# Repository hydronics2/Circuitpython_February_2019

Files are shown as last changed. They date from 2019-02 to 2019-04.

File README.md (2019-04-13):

# Circuitpython_February_2019
This is a soldering and programming class in Circuitpython

[github.com/hydronics2/circuitpython_february_2019](https://github.com/hydronics2/Circuitpython_February_2019)

This class occurs in two parts -- Soldering and Programming.

We'll be soldering parts and headers  onto a custom printed circuit board(PCB).  
Once complete, the microController (an Adfruit development board -  [ItsyBitsy M0](https://www.adafruit.com/product/3727)) sockets onto the PCB female headers.
When you connect the Adafruit M0 microController to your computer it shows up as an external hard drive with pre-loaded example scripts.

[Soldering Tutorial](https://github.com/hydronics2/Circuitpython_February_2019/blob/master/soldering/README.md)

[Programming Tutorial](https://github.com/hydronics2/Circuitpython_February_2019/blob/master/programming/README.md)

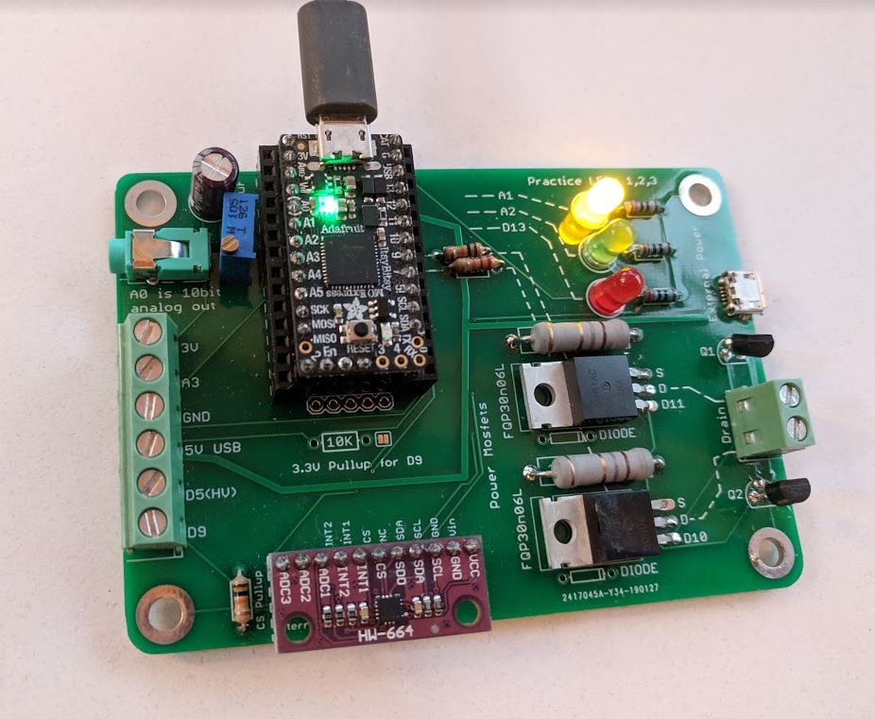
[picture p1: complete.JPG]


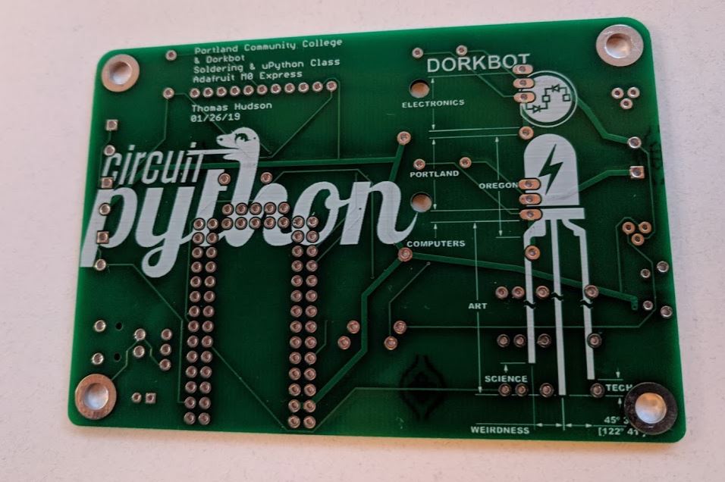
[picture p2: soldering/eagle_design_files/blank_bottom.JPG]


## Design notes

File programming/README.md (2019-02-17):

# CircuitPython

I uploaded the above python scripts onto your Adafruit M0 board. When you plug the unit into your board it appears as a flash drive.

Download and install the [MU editor](https://learn.adafruit.com/welcome-to-circuitpython/installing-mu-editor) if you have not done so already.

## code.py
LOAD the code.py script. Code.py determines which scripts run. Uncomment the files you would like to run.
###
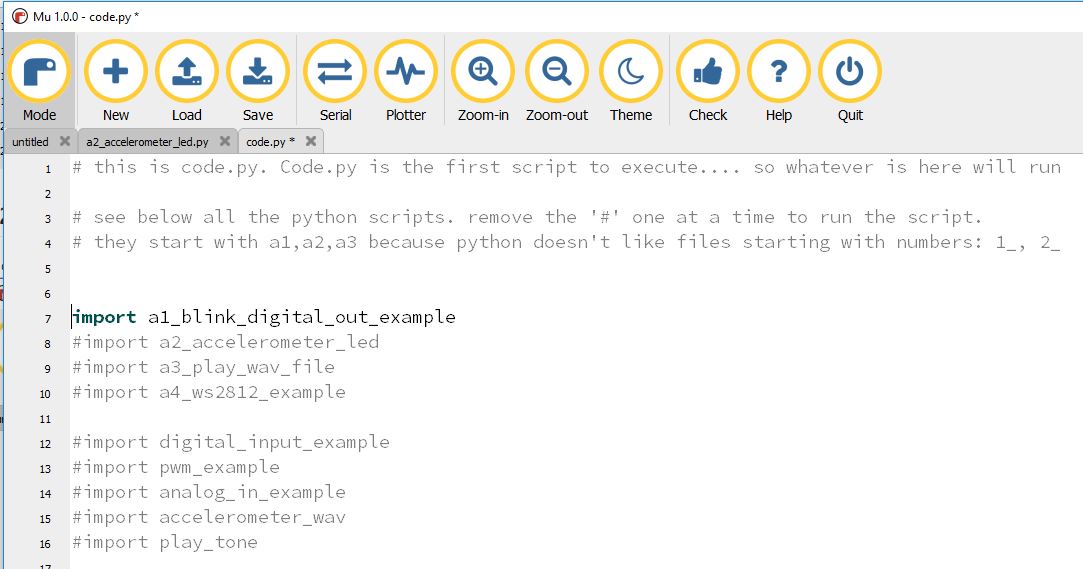
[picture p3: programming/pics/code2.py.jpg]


# 
## a1_blink_digital_out_example
LOAD the "a1_blink_digital_out_example.py" script that's currently running. It blinks the LED on pin 13. An internal LED also blinks. Try blinking the other LEDs on pins A1 and A2. In my case I labeled them greenLed and yellowLed. Hit the SERIAL button to see the print statements.
###
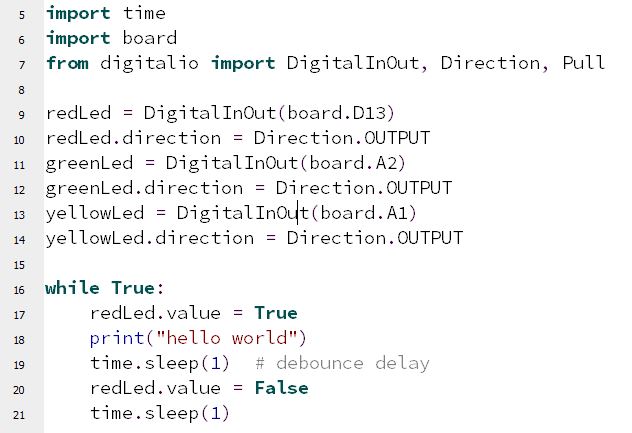
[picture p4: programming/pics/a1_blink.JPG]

# 

## a2_accelerometer_led
Modify the code.py script and uncomment a2_accelerometer_led.
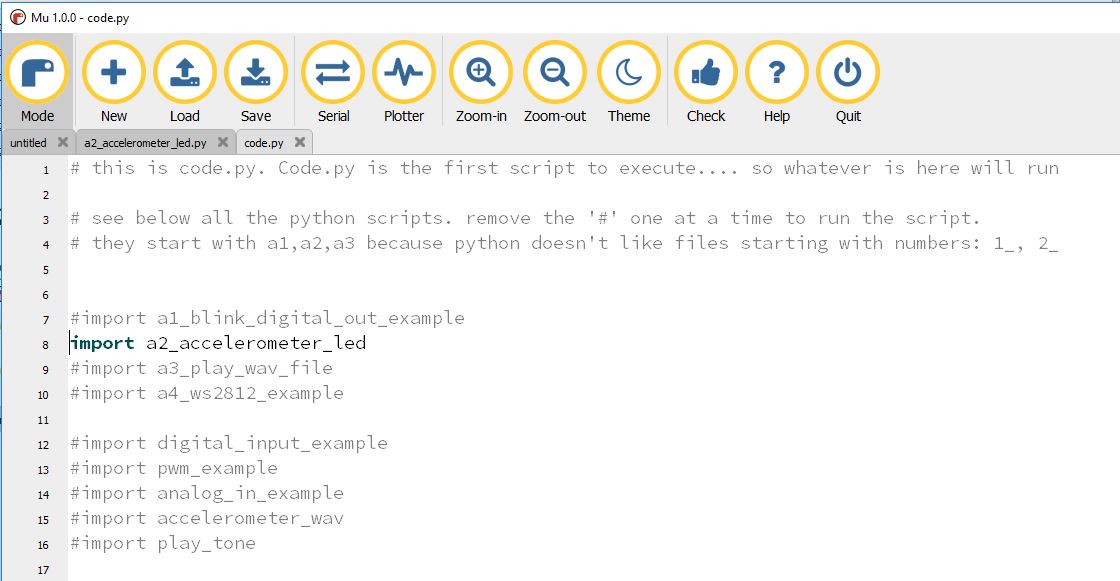
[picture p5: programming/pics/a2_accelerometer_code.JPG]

###
The script lights up an LED with increasing tilt.
When you use a print statement with double perenthesis it allows the data to the plotter; such as, print((x,y,z)).
###
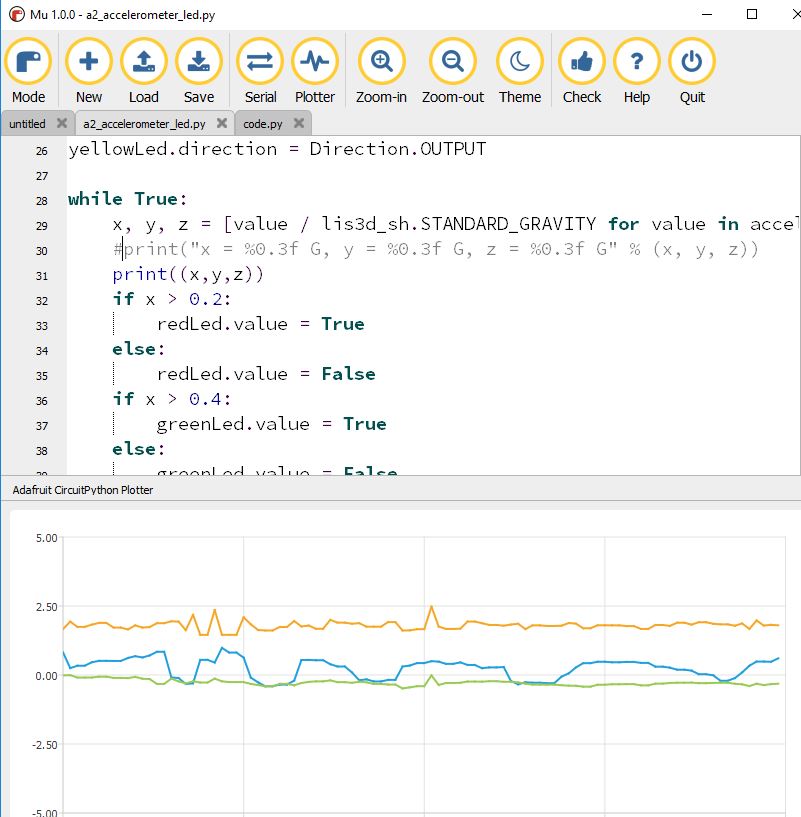
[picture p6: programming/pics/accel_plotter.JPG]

# 

## a3_play_wav_file
Modify the code.py script and unomment a3_play_wav_file
###
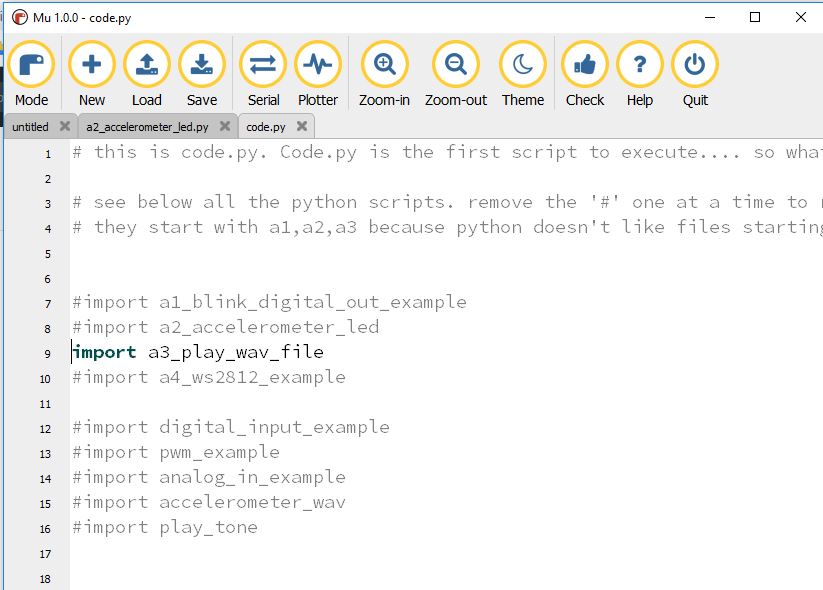
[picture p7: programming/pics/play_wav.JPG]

###
5 wav files for you try. They are in the sounds folder. Uncomment the files to play each one.. and/or make your own. 
Save files as 22 KHz or less because the circuitpython can't handle more data than that and the DAC(digital-to-analog-converter) output is 10-bit so anything over 16-bit will just take up room without better quality.
###
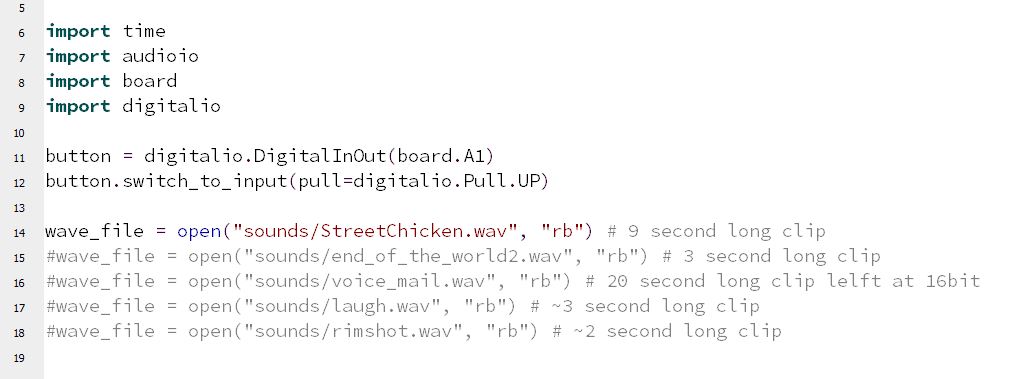
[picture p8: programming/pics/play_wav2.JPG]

# 

## a4_ws2812_example
Modify the code.py script and unomment a4_ws2812_example
###
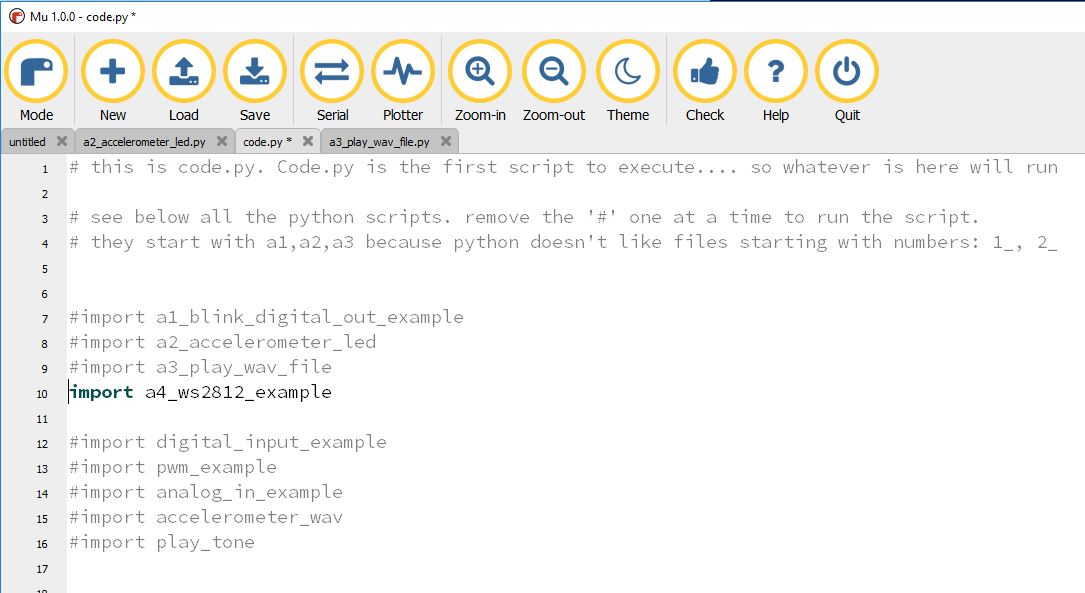
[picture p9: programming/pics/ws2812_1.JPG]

###
solder three leads onto your LED strip on the correct side (start of the arrow). Insert the LEDs into the screw headers.
LOAD the sketch and modify the "num_leds" variable to the number of LEDs in your strip.
The red, green, and blue LEDs can have values from 0 to 255.
###
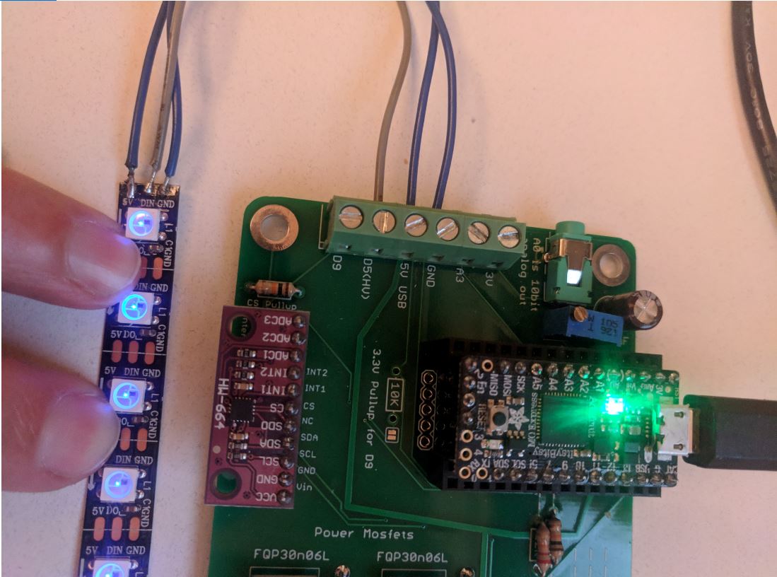
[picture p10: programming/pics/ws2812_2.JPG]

# 

## analog_in_example
Modify the code.py script and unomment analog_in_example.
Try plugging in both the potentiometer and photocell to see how the analog-to-digital converter(ADC) on pin A3 interprets the signals.
###
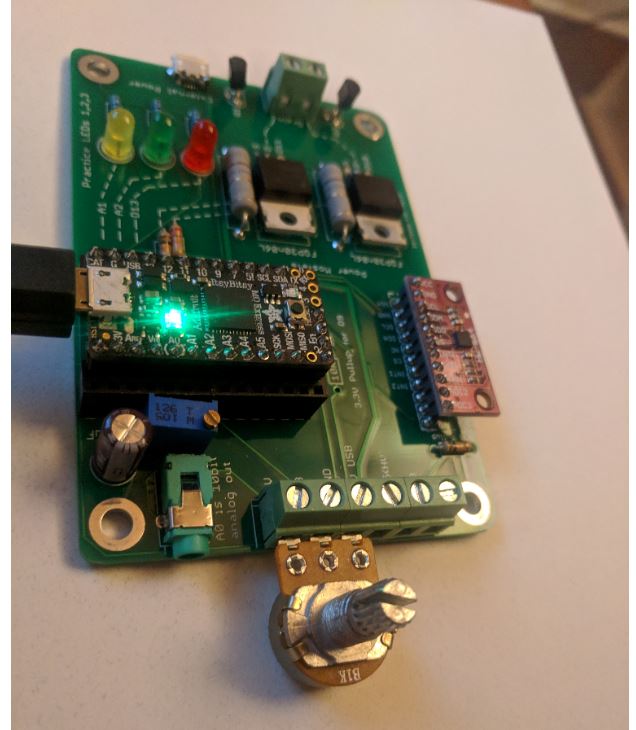
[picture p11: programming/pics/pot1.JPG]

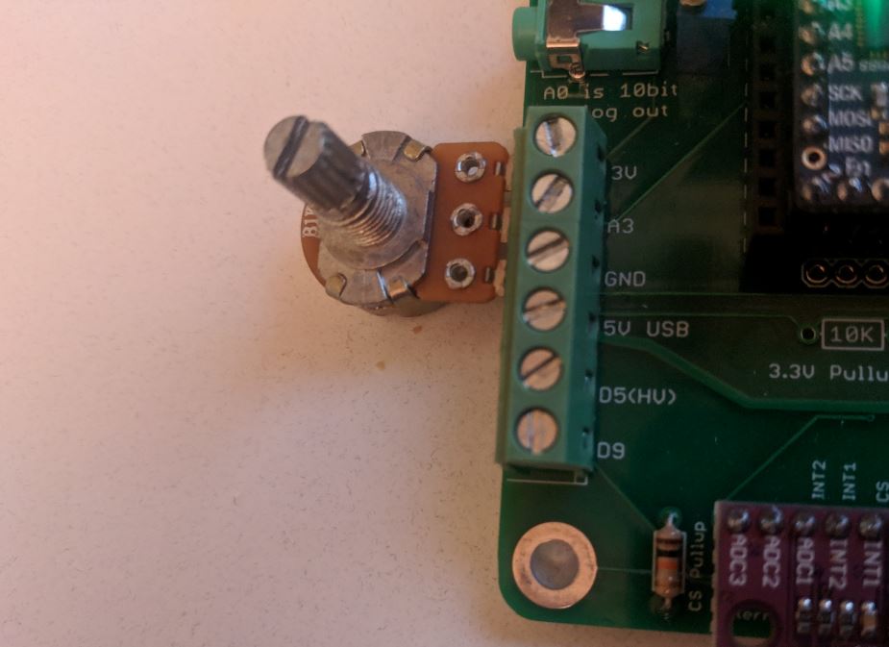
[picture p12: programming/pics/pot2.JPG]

###
Make the photocell voltage divder using a photocell and a 10k resistor.
###
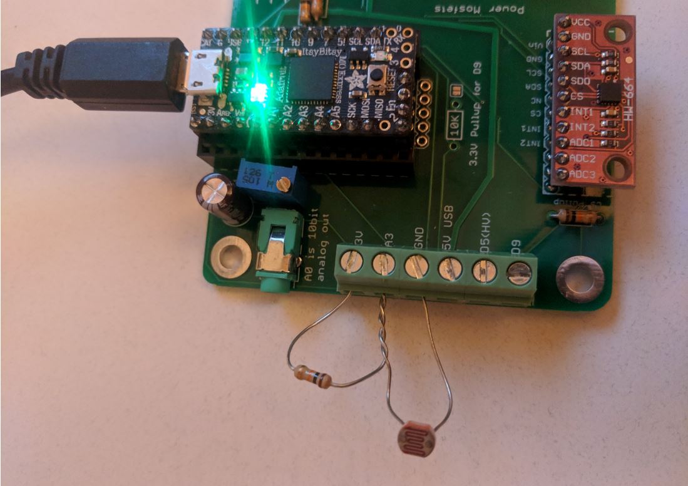
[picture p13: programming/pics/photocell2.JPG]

You can see the data on the plotter by using the print statement with extra perenthesis and a comma, "print((analogValue,))"
###
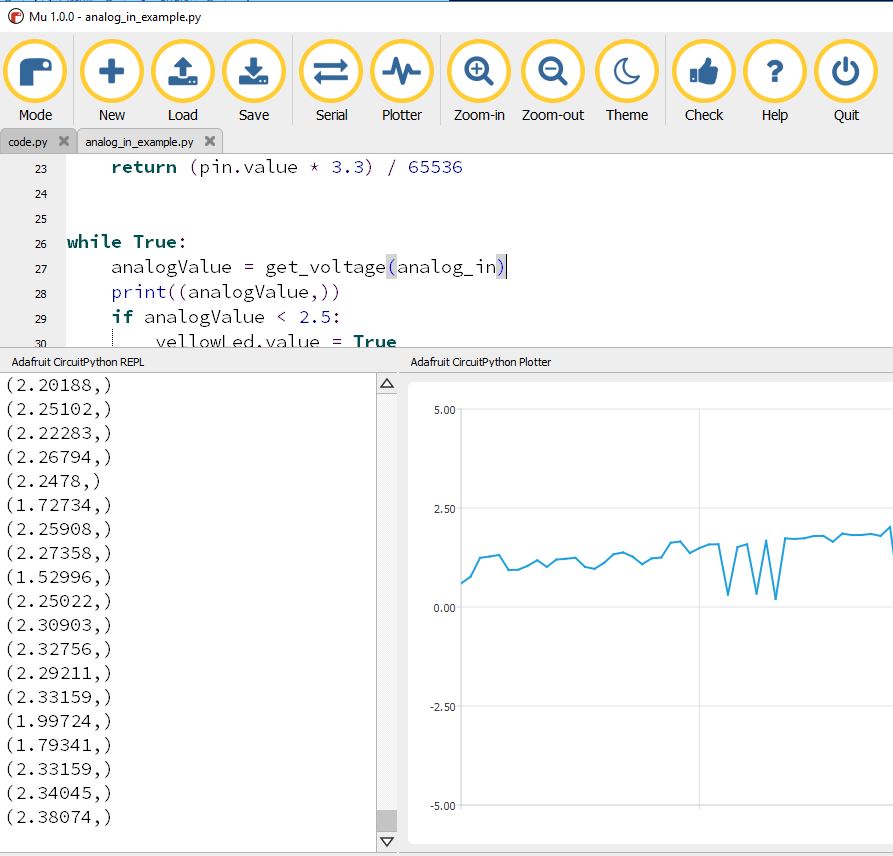
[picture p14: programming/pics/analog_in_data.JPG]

#

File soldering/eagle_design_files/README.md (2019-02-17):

# Printed Circuit Board

This circuit board was designed in Eagle.

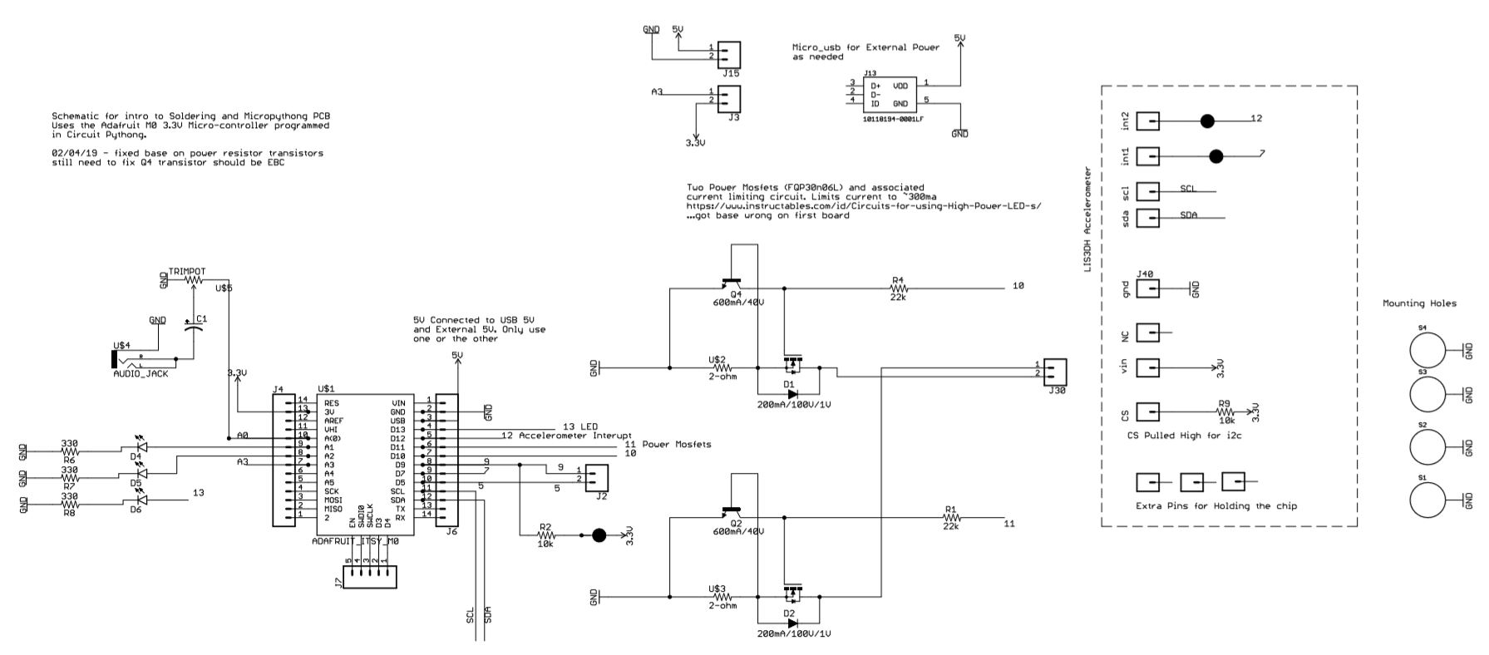
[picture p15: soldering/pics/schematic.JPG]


02/16/19 
- corrected the base transistor. It needs to be connected to the source pin of the mosfet. Have not routed the signal. Incorrectly routed on version 1 board
- still need to correct the Q1 and Q2 silkscreen. Sparkfun's NPN trnsistor did not use emitter-base-collector??? ridiculous!

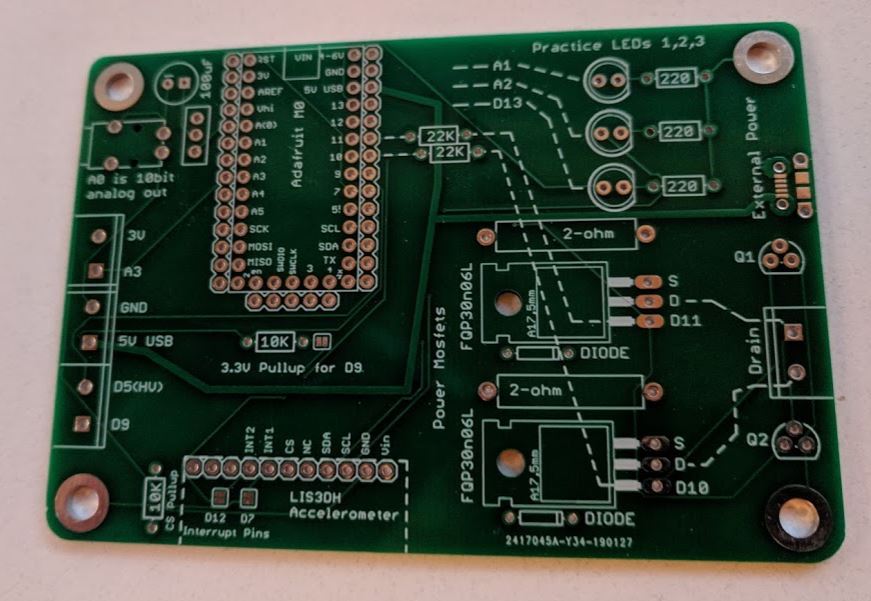
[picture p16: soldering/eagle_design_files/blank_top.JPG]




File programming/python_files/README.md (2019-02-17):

# Circuitpython files

[Adafruit Tutorial](https://learn.adafruit.com/circuitpython-essentials)

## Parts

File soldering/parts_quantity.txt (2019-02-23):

itsybits qty(8)
WS8212 Strip ~5meters
2-pin 5.08mm headers qty(122)
1/8" audio jacks qty(76)
16+ pins male headers qty(62)
16pin dual row female headers qty(101)
USB micro cables mix qty(15) not all tested
100k trim pots qty(7)
10k potentiometers qty(12)
5mm LEDs qty(1000)
photocels qty(50+)
10K and 220ohm resistors... qty(plenty?)
10uF 50v and 10uf 25V qty(~100)
pin-to-pin Jumper wires qty(100+)

LIS3D_SH Accelerometers qty(3)
usb drives qty(5)
circuitPython PCBs 1/26/10 qty(4)

future class
2ohm 1/2W resistors qty(100) S2HCT-ND
FQP power mosfets qty(unopened package ~100?)
large 12mm buttons qty(40)

Need
leaded solder

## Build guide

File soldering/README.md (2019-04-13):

# Soldering

Parts list
- [itsybitsy M0](https://www.adafruit.com/product/3727)
- [LIS3DSH Accelerometer](https://www.aliexpress.com/item/CJMCU-LIS3DSH-High-resolution-Three-axis-Accelerometer-Triaxial-Accelerometer-Module-LIS3DH/32879796761.html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)
- [14 pin double row headers](https://www.aliexpress.com/item/100-pcs-2-54-mm-0-100-Pitch-2x14-28-Pin-Dual-Row-PCB-Female-Header/32807834427.html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)
- [2-pin terminal blocks](https://www.aliexpress.com/item/50PCS-PCB-Screw-Terminal-Block-Connector-KF127-2P-pitch-5-08MM-0-2inch-Green-5mm-KF127/32791211110.html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)
- [WS2812 LED Strip](https://www.aliexpress.com/item/5m-DC5V-WS2812B-led-pixel-srip-non-waterproof-74pcs-WS2812B-M-with-60pixels-BLACK-PCB-only/1667439010.html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)
- [FQP30N06 Power Mosfet TO-220](https://www.aliexpress.com/item/Free-shipping-100pcs-lot-FQP30N06-30N06-TO-220-IC/32863833006.html?)
- [3.5 mm (1/8") jack](https://www.aliexpress.com/item/Free-shipping-100pcs-lot-FQP30N06-30N06-TO-220-IC/32863833006.html?)
- [trim pot ~1K](https://www.aliexpress.com/item/Free-shipping-100PCS-3296W-1-103LF-3296W-3296-10K-OHM-Trimpot-Trimmer-Potentiometer/32285032567.html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)
- 100uF 16V Capacitor
- 10k pullup resistors
- 220 ohm current limiting LED resistors
- [2ohm, 1/2watt Power Sensing Resistor](https://www.digikey.com/product-detail/en/stackpole-electronics-inc/CFM12JT2R00/S2HCT-ND/2617415)
- [PN2222A Transistor](https://www.aliexpress.com/item/100pcs-PN2222A-TO-92-PN2222-TO-92/32888878276.html?)
- [micro USB connector](https://www.digikey.com/product-detail/en/amphenol-icc-fci/10118194-0001LF/609-4618-6-ND/2785383)

[Here's the schematic](https://github.com/hydronics2/Circuitpython_February_2019/blob/master/soldering/eagle_design_files/PCB_schematic.pdf)

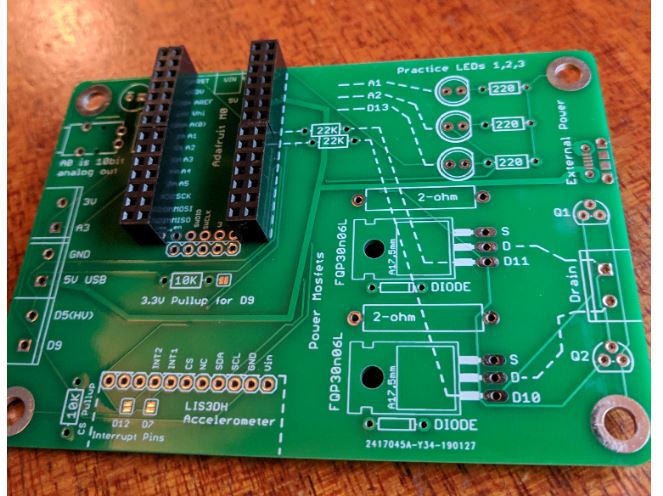
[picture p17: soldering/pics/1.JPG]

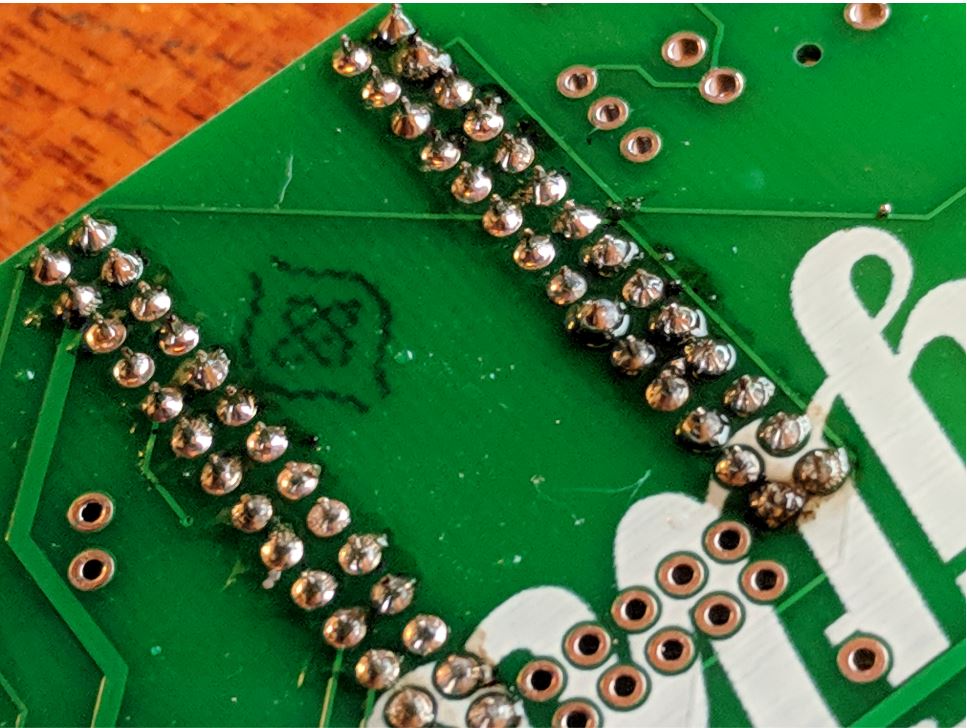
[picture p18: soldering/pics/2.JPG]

Solder on pins should look concave. NOT BALLS. Use your solding iron to wick away excess solder.
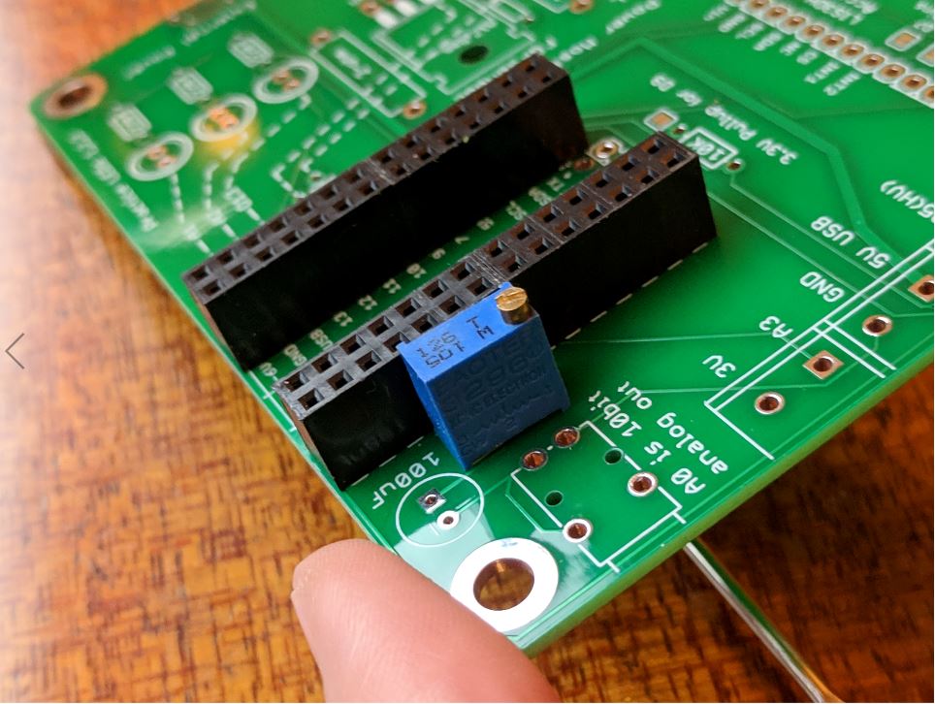
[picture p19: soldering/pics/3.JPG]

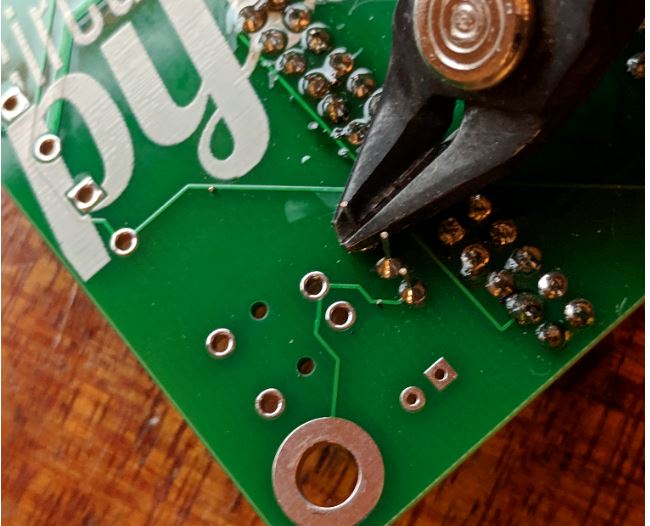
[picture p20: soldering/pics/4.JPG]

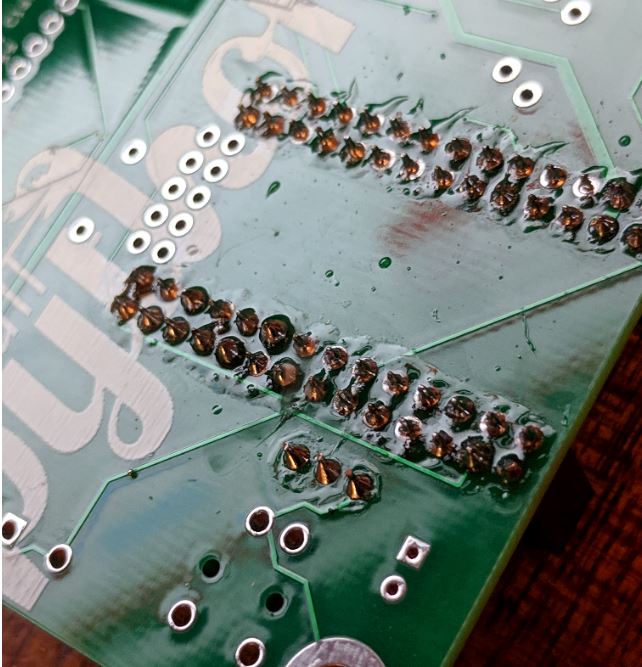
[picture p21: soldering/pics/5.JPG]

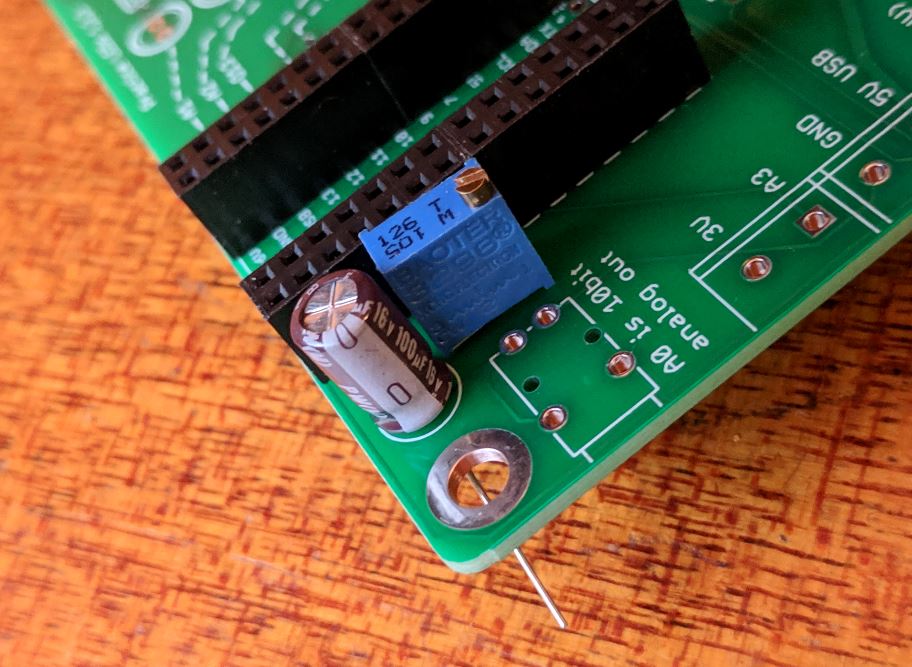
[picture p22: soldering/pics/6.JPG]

Your cap maybe 47uF cause that's what I had although the adafruit tutorial recomends 100uF 16V.
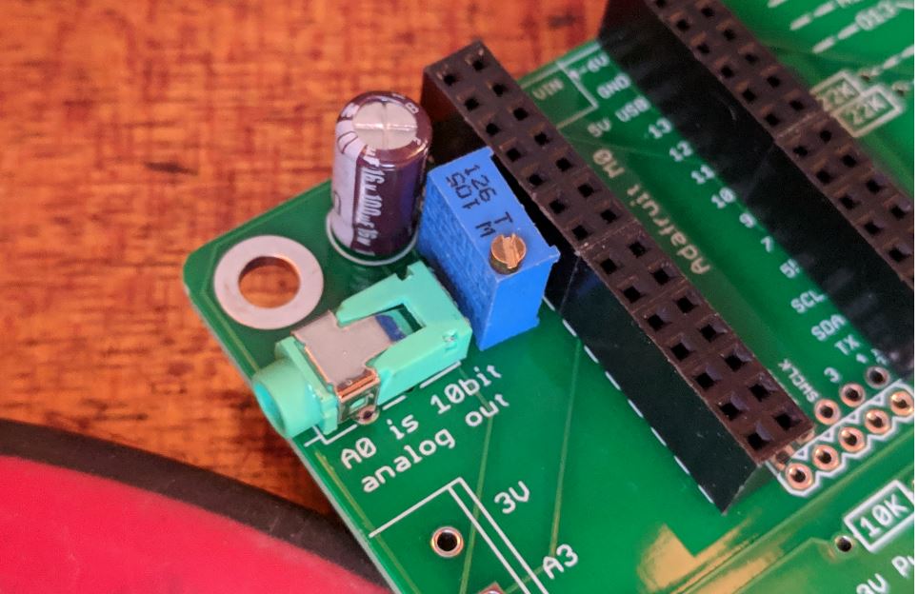
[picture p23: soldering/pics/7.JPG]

[](https://github.com/hydronics2/Circuitpython_February_2019/blob/master/soldering/pics/8.JPG)
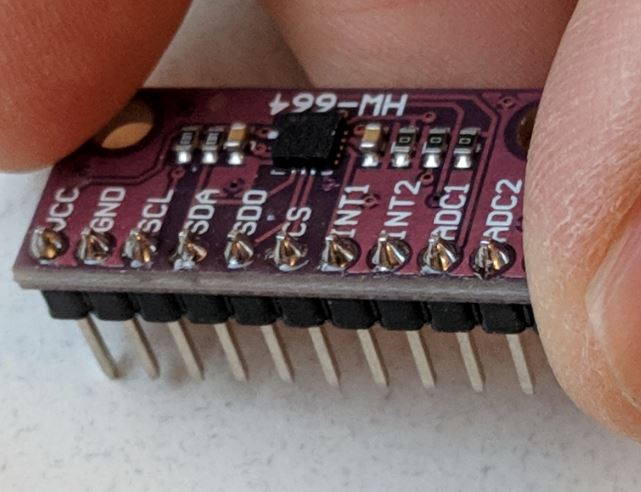
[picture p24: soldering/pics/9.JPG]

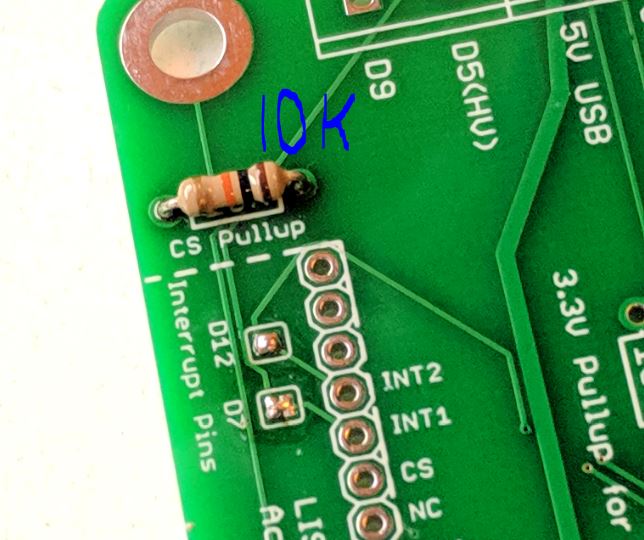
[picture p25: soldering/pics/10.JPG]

The resistor color band for 10K is brown-black-orange. The last color (gold in this picture) indicates tollerance (1%, 5%, etc).
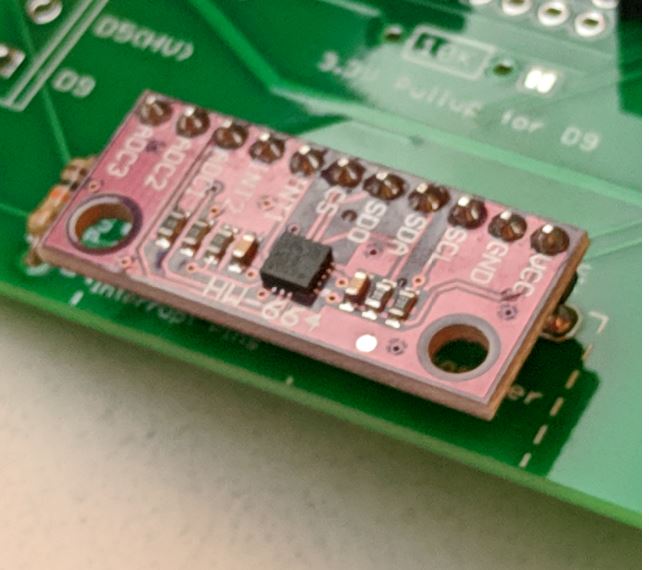
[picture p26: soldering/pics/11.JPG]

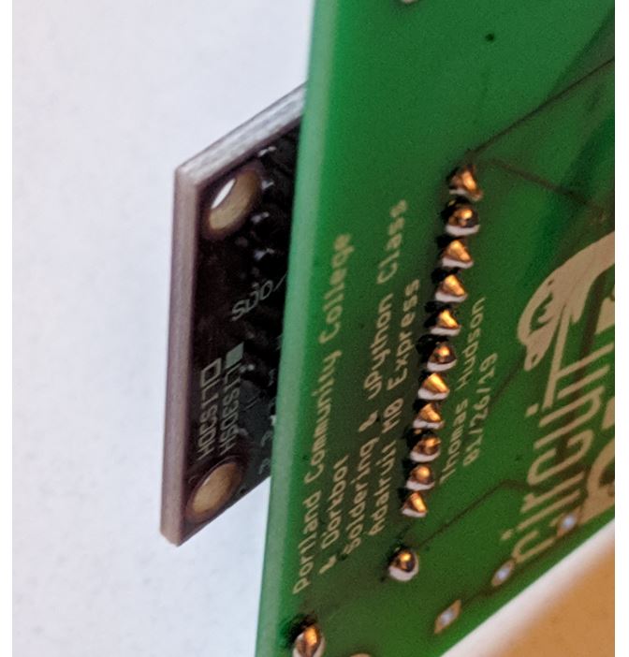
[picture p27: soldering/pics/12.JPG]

Soldering the accelerometer board ~1/8" above the PCB keeps the pins looking nice on the bottom. 
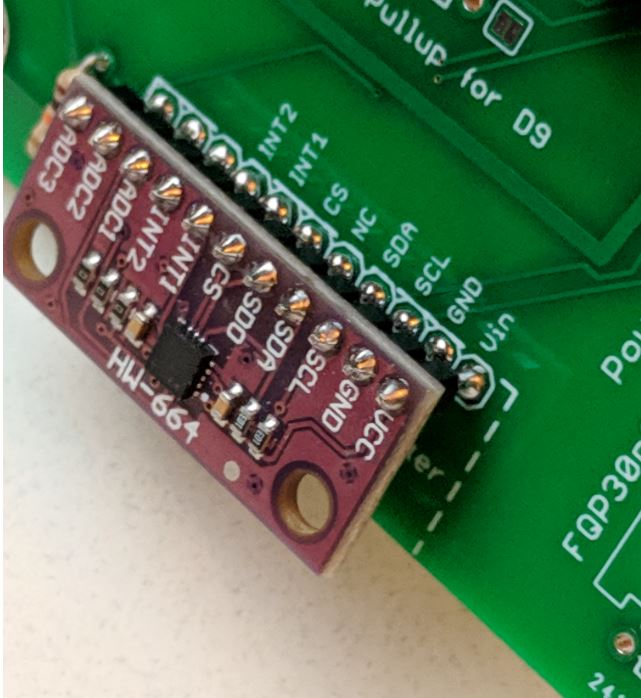
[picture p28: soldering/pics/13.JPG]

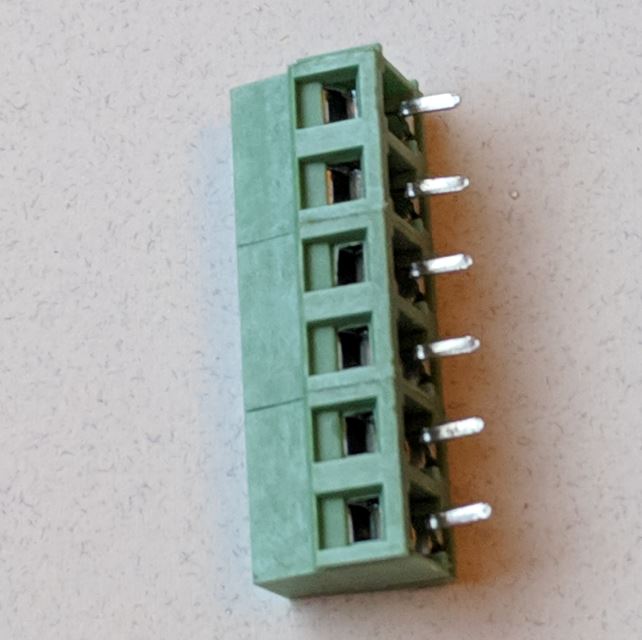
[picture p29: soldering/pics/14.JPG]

These 5.08mm screw terminals slide together.
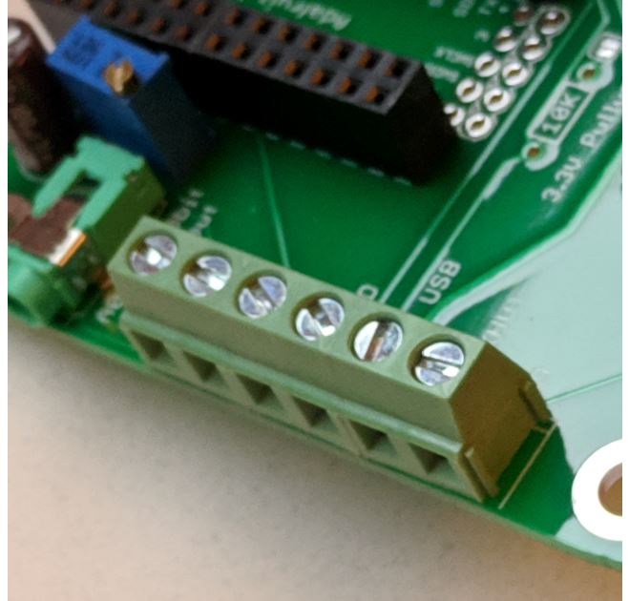
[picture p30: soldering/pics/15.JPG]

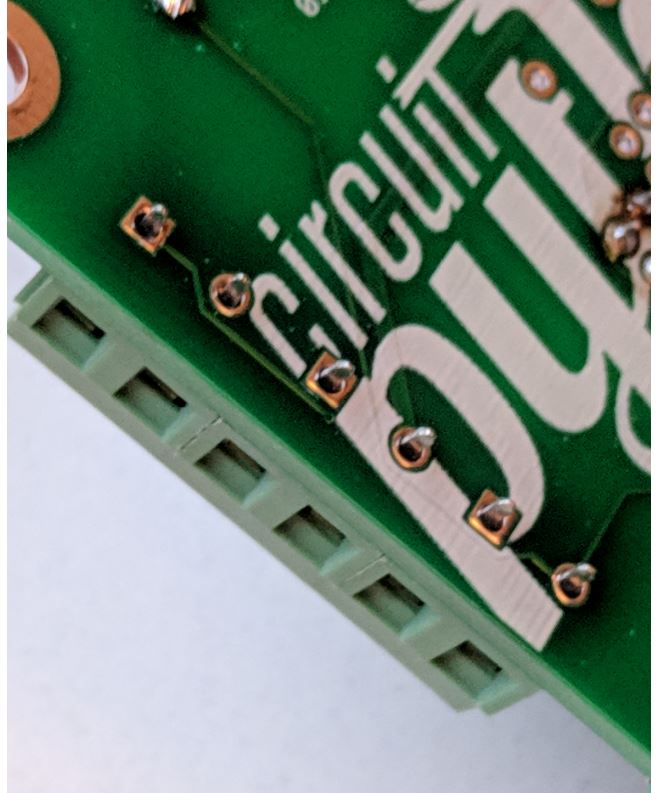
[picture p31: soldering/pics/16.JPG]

Solder all those Pins!
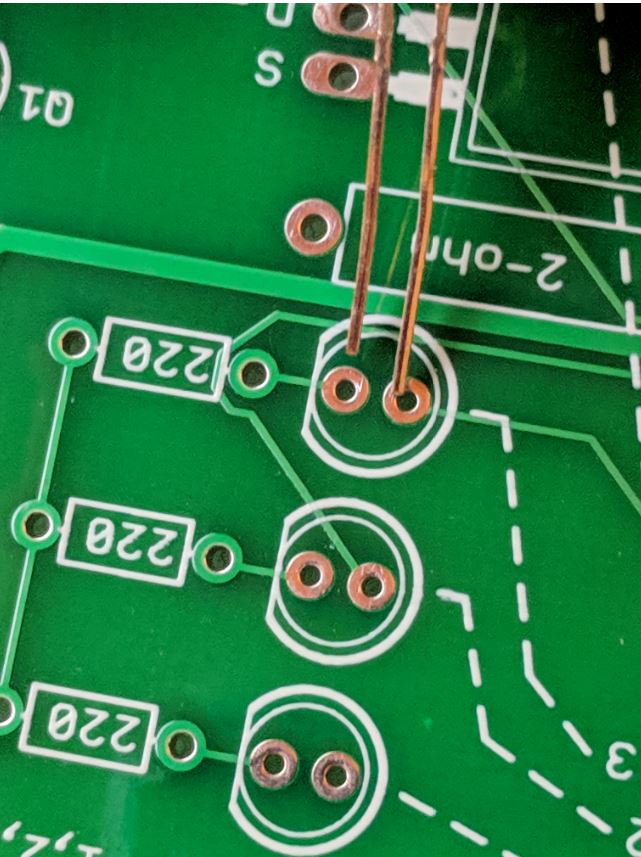
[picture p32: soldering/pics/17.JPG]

Choose wichever color LEDs you like. The longer lead is positive.
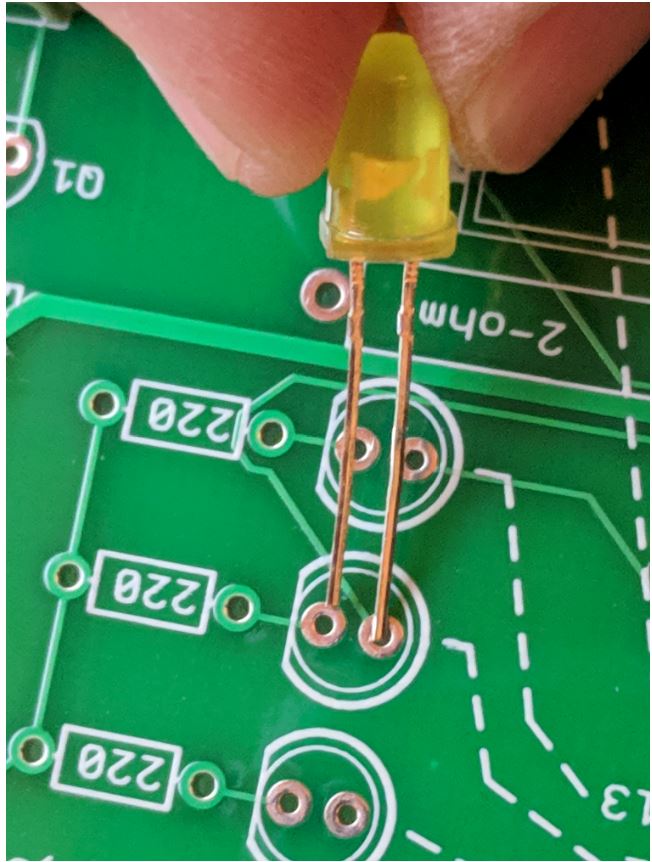
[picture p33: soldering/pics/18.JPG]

The notch in the LED is negative and matches the notch in the silkscreen.
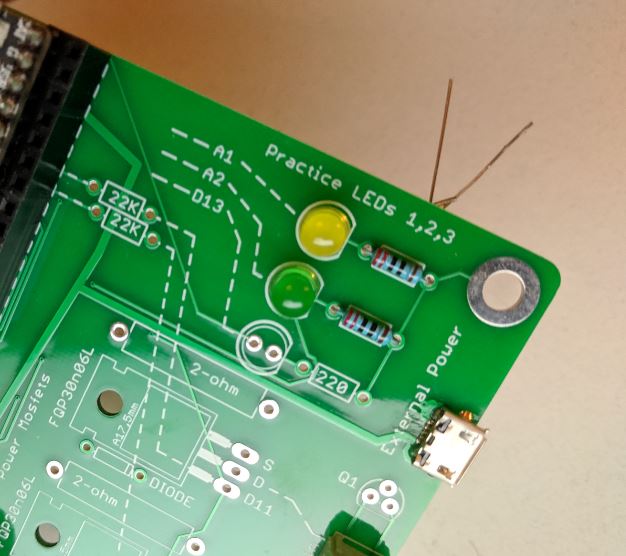
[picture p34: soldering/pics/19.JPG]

The current limiting resistors for the LEDs is 220ohms. The color band for 220 is red-red-black.
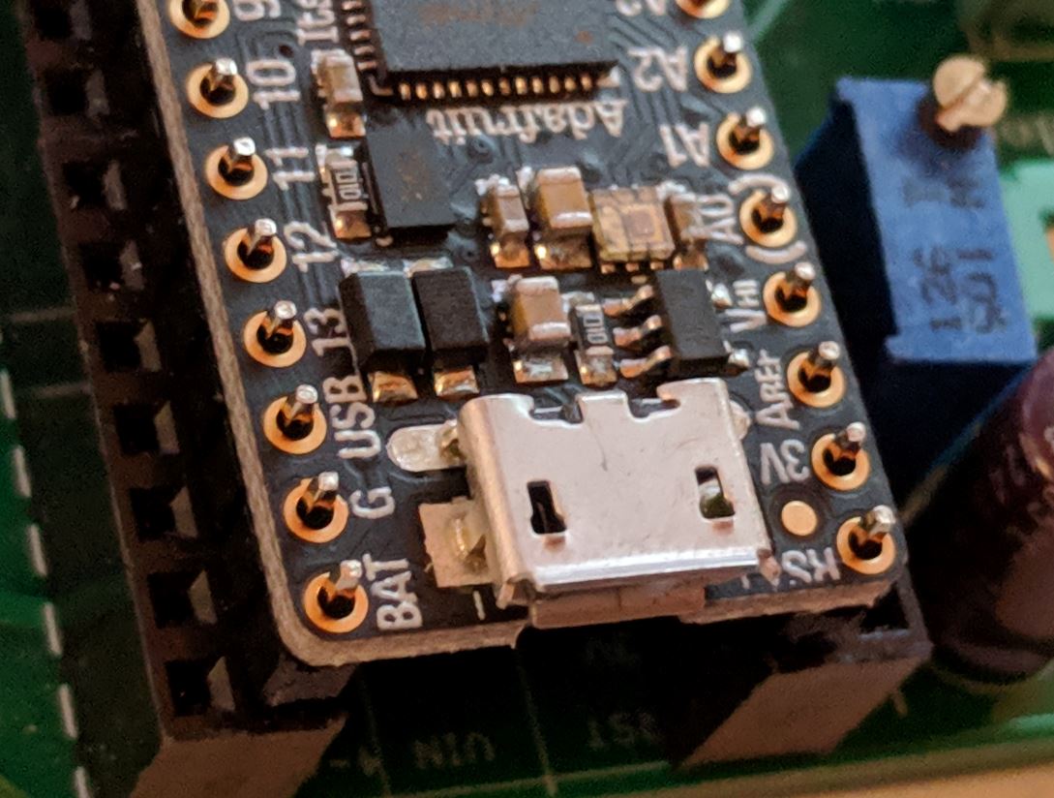
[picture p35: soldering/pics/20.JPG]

Solder all those Pins!
Break the male headers into 14 pins to match the length of the uController and solder the pins to the uController.
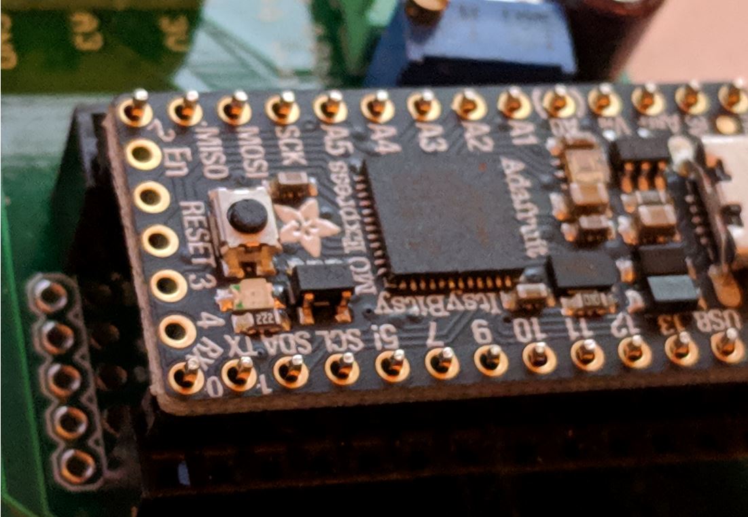
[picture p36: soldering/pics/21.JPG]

Solder all those Pins!
Break 2 pins off the 16pin male headers to get 14 pins is all you need. You're Done.
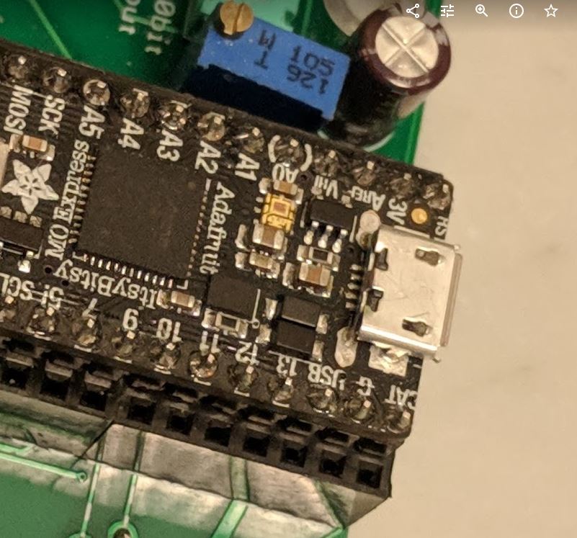
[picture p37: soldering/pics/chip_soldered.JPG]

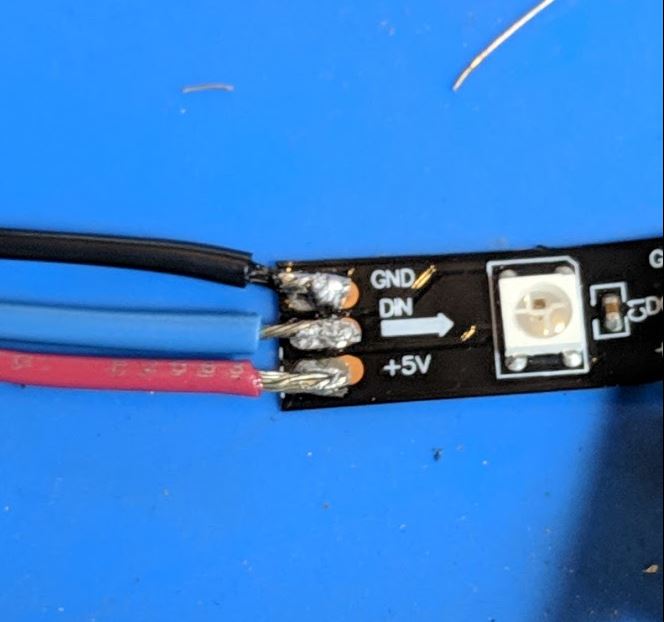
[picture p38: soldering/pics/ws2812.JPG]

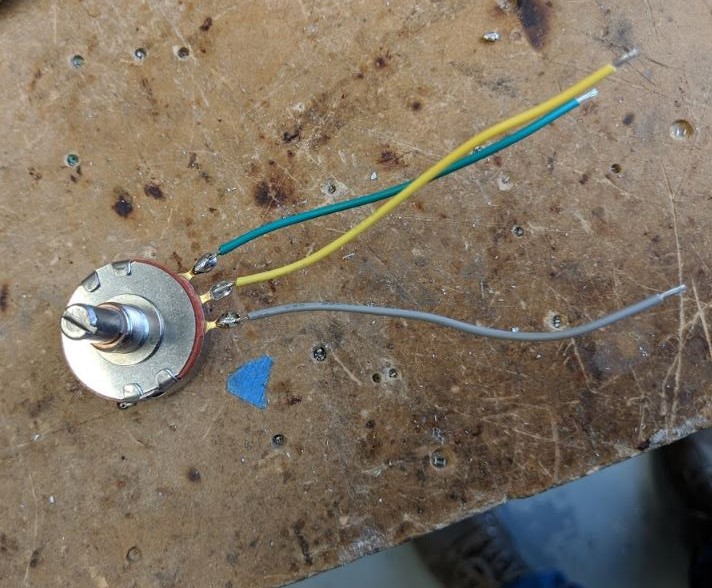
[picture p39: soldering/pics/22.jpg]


Solder 3 wires onto the potentiometer.

That's it. We're all finished! We're leaving a few footprints unpopulated for this class.

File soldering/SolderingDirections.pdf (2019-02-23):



Solder on pins should look concave. NOT BALLS. Use your solding iron to wick away excess solder.





Your cap maybe 47uF cause that's what I had although the adafruit tutorial recomends 100uF 16V.

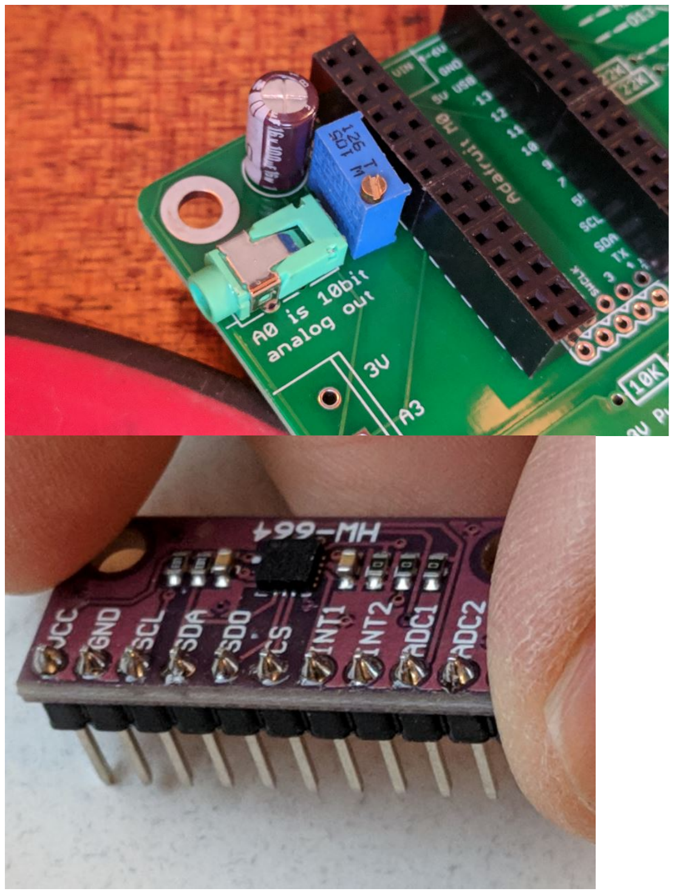
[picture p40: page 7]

The


resistor color band for 10K is brown-black-orange. The last color (gold in this picture) indicates tollerance (1%, 5%, etc).


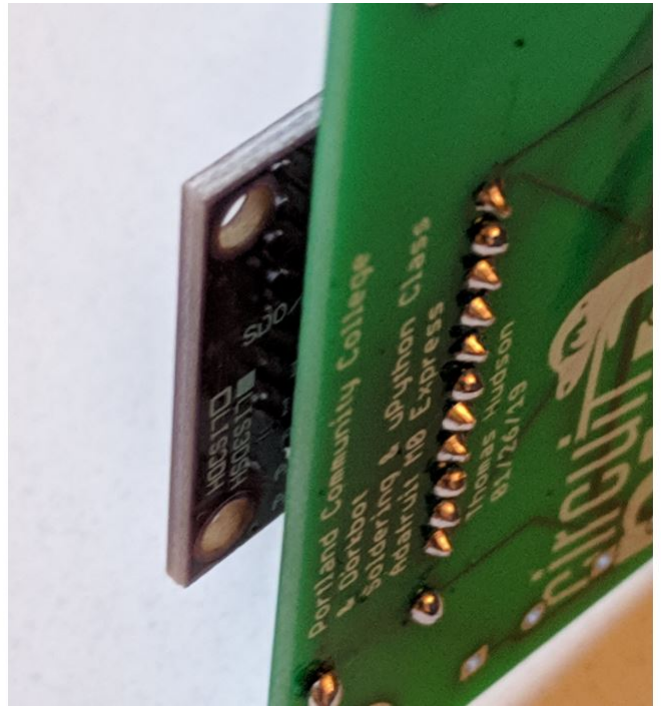
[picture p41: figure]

Soldering the accelerometer board ~1/8" above the PCB keeps the pins looking nice on the bottom.


These


5.08mm screw terminals slide together.


Choose
wichever color LEDs you like. The longer lead is positive.


The notch
in the LED is negative and matches the notch in the silkscreen.

The current


limiting resistors for the LEDs is 220ohms. The color band for 220 is red-red-black.


Break the male headers into 14 pins to match the length of the uController and solder the pins to the uController.


Break 2 pins off the 16pin male headers to get 14 pins is all you need. You're Done.



We're not going to solder the rest of the parts unless we have more time or you want to do extra.

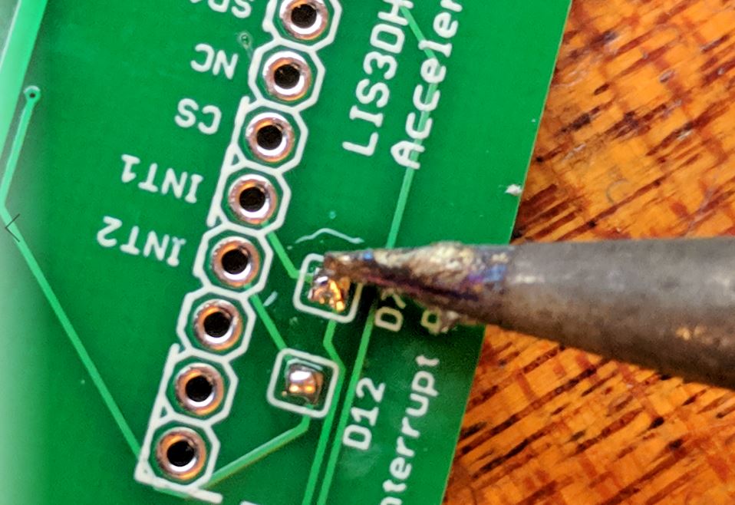
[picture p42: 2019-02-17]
soldering/pics/8.JPG

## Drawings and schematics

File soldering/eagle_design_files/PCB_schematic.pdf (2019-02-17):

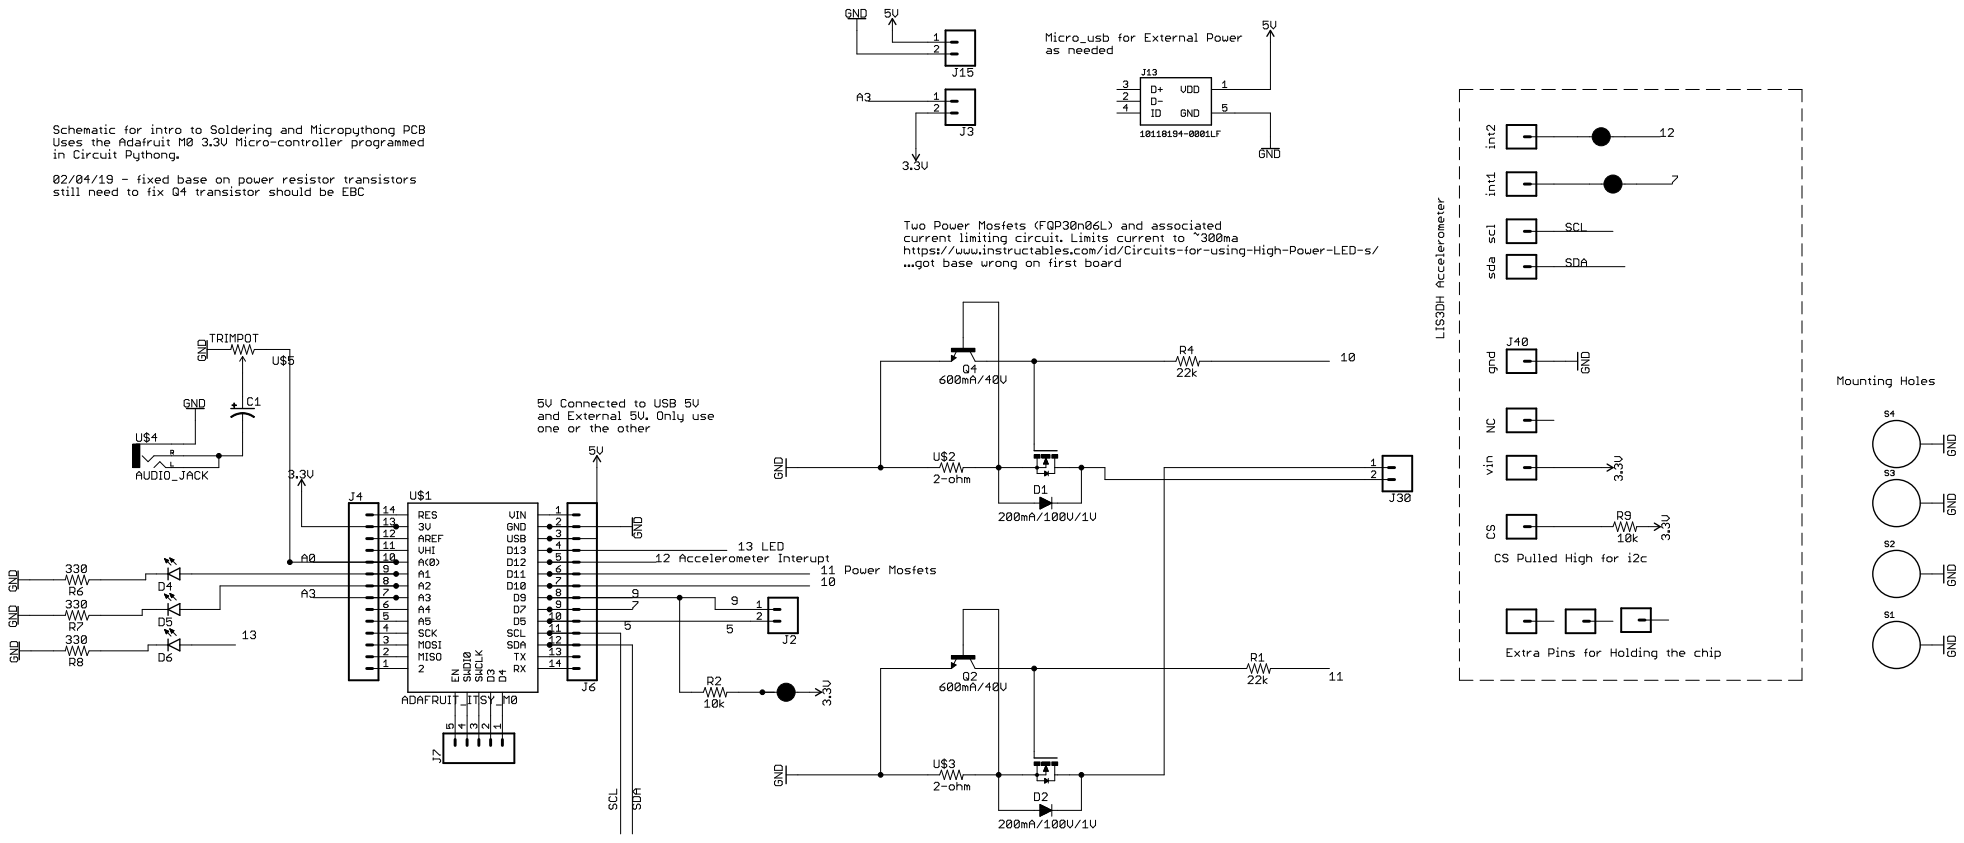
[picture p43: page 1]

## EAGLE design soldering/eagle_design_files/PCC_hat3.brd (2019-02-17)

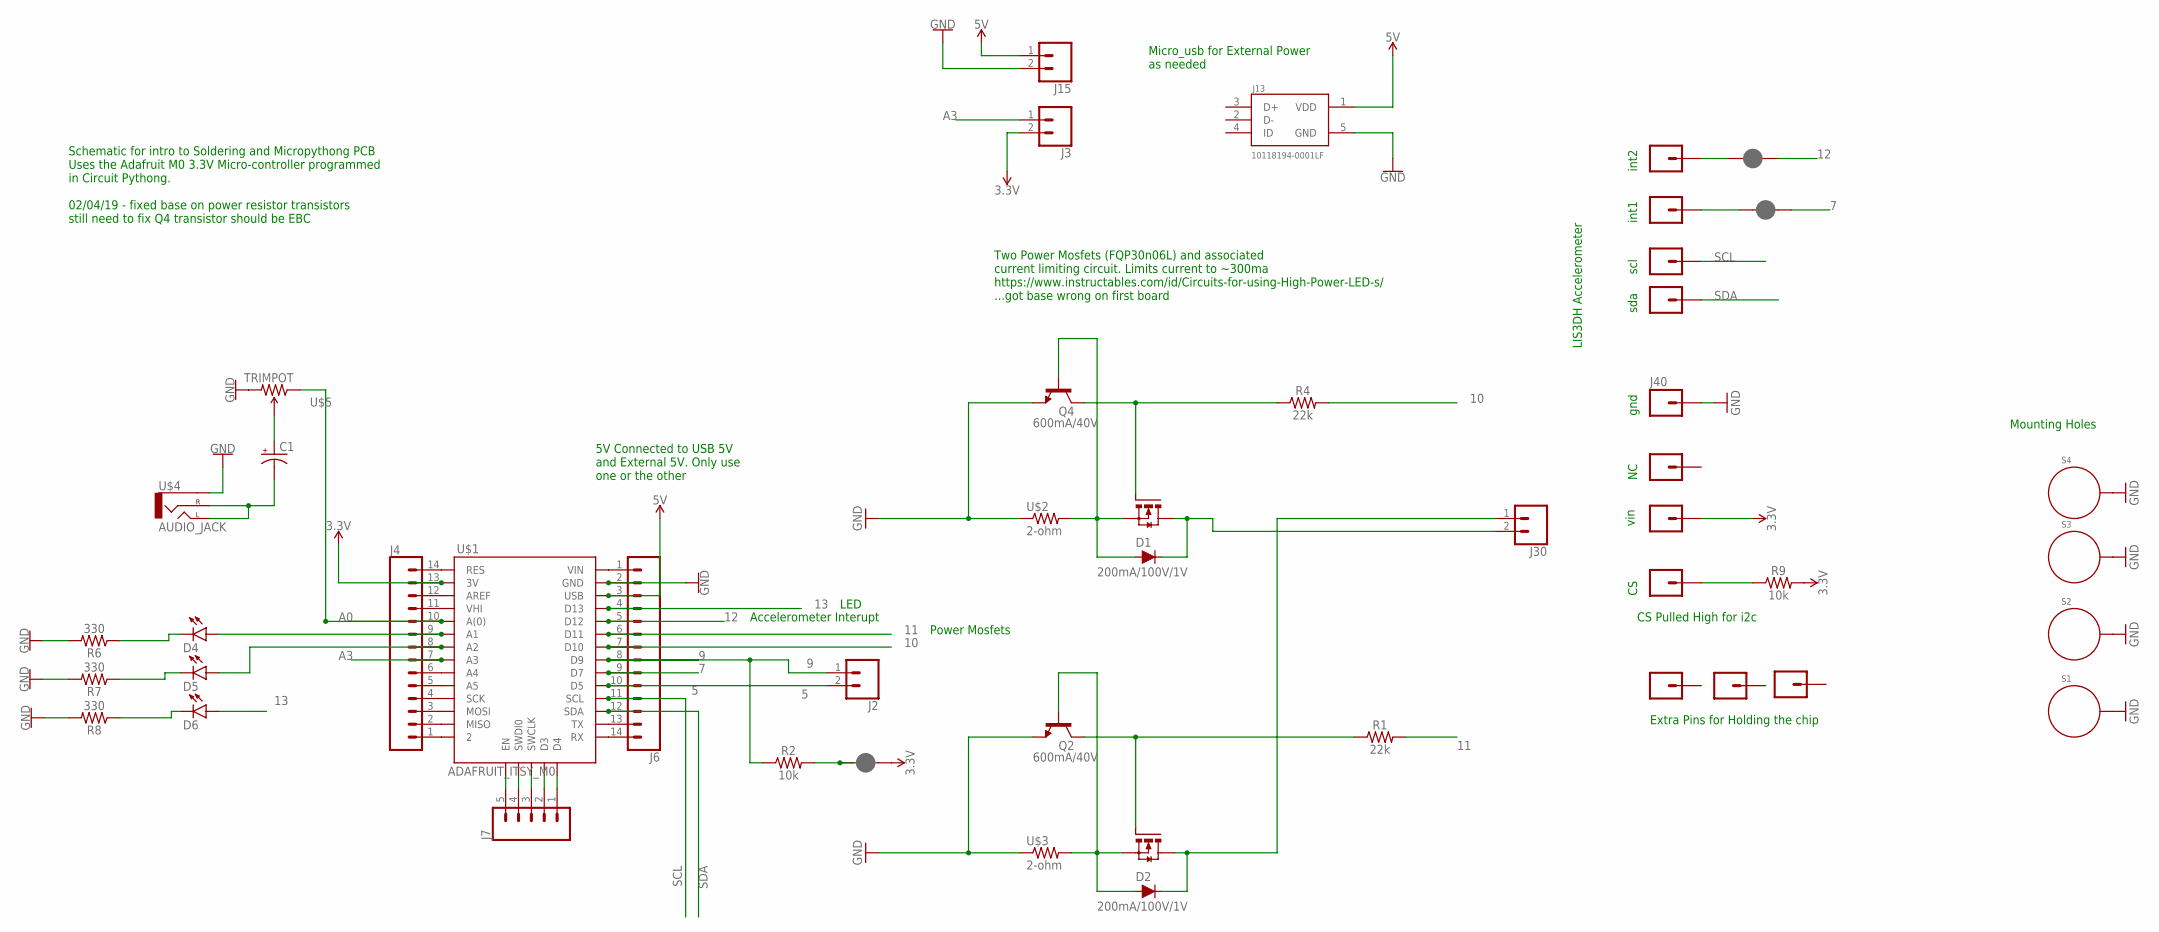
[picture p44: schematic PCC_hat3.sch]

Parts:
C1: CAP_POLPTH1; CPOL-RADIAL-100UF-25V
D1, D2: 200mA/100V/1V; DIODE-1N4148-KIT
D4, D5, D6: LED5MM
J2, J3, J15, J30: CONN_025MM; SCREWTERMINAL-5MM-2
J4, J6: CONN_14; 1X14
J5, J8, J9, J10, J11, J12, J39, J40, J42, J43, J44: M01PTH; 1X01
J7: CONN_05; 1X05
J13: 10118194-0001LF; FRAMATOME_10118194-0001LF
JP1, JP2, JP3: JUMPER-SMT_2_NC_PASTE_SILK; SMT-JUMPER_2_NC_PASTE_SILK
Q1, Q3: IRFI540NPBF; TO220BH
Q2, Q4: 600mA/40V; TO-92
R1, R4: 22k; AXIAL-0.3-KIT
R2, R9: 10k; AXIAL-0.3-KIT
R6, R7, R8: 330; AXIAL-0.3-KIT
S1, S2, S3, S4: STANDOFF_ELECTRICAL; STANDOFF-ELECTRICAL
U$1: ADAFRUIT_ITSY_M0; ADAFRUIT_ITS_M0
U$2, U$3: 2-ohm; RESISTOR_5W_PT
U$4: AUDIO_JACK; 1/8"AUDIO_JACK
U$5: TRIMPOT; 1X03_TRIMPOT

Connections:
3.3V: J3.2, J4.13, J5.1, JP3.2, R9.P$2 (2), U$1.3V
5: J2.2, J6.10, U$1.D5
5V: J6.3, J13.1 (VDD), J15.1, U$1.USB
7: J6.9, JP1.2, U$1.D7
9: J2.1, J6.8, R2.P$1 (1), U$1.D9
10: J6.7, R4.P$2 (2), U$1.D10
11: J6.6, R1.P$2 (2), U$1.D11
12: J6.5, JP2.2, U$1.D12
13: D6.A, J6.4, U$1.D13
A0: J4.10, U$1.A0 (A(0)), U$5.1 (CCW)
A3: J3.1, J4.7, U$1.A3
EXTERNAL_5V: J6.1, U$1.VIN
GND: J6.2, J13.5 (GND), J15.2, J40.1, Q2.3 (E), Q4.3 (E), R6.P$2 (2), R7.P$2 (2), R8.P$2 (2), S1.P1, S2.P1, S3.P1, S4.P1, U$1.GND, U$2.P$1 (1), U$3.P$1 (1), U$4.GND (SLEEVE), U$5.3 (CW)
unnamed: JP3.1, R2.P$2 (2)
unnamed: D4.K (C), R6.P$1 (1)
unnamed: J7.1, U$1.D4
unnamed: C1.2 (-), U$4.LEFT_TIP_1 (LEFT), U$4.RIGHT
unnamed: J4.2, U$1.MISO
unnamed: J4.3, U$1.MOSI
unnamed: J4.4, U$1.SCK
unnamed: J4.5, U$1.A5
unnamed: J4.6, U$1.A4
unnamed: C1.1 (+), U$5.2 (WIPER)
unnamed: D5.A, J4.8, U$1.A2
unnamed: D4.A, J4.9, U$1.A1
unnamed: D5.K (C), R7.P$1 (1)
unnamed: J4.11, U$1.VHI
unnamed: J4.12, U$1.AREF
unnamed: J4.14, U$1.RES
unnamed: D2.C, J30.1, Q1.D
unnamed: D1.A, Q3.S, Q4.2 (B), U$2.P$2 (2)
unnamed: J11.1, JP2.1
unnamed: D6.K (C), R8.P$1 (1)
unnamed: J6.13, U$1.TX
unnamed: J6.14, U$1.RX
unnamed: J7.2, U$1.3 (D3)
unnamed: J7.3, U$1.SWCLK
unnamed: J7.4, U$1.SWDI0
unnamed: J7.5, U$1.EN
unnamed: J44.1, JP1.1
unnamed: J8.1, R9.P$1 (1)
unnamed: D2.A, Q1.S, Q2.2 (B), U$3.P$2 (2)
unnamed: Q3.G, Q4.1 (C), R4.P$1 (1)
unnamed: Q1.G, Q2.1 (C), R1.P$1 (1)
unnamed: J4.1, U$1.2
unnamed: D1.C, J30.2, Q3.D
SCL: J6.11, J43.1, U$1.SCL
SDA: J6.12, J42.1, U$1.SDA

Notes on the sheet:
vin
gnd
sda
scl
int1
LIS3DH Accelerometer
CS Pulled High for i2c
int2
Power Mosfets
LED
Extra Pins for Holding the chip
Two Power Mosfets (FQP30n06L) and associated current limiting circuit. Limits current to ~300ma https://www.instructables.com/id/Circuits-for-using-High-Power-LED-s/ ...got base wrong on first board
Accelerometer Interupt
Mounting Holes
Micro_usb for External Power as needed
5V Connected to USB 5V and External 5V. Only use one or the other
Schematic for intro to Soldering and Micropythong PCB Uses the Adafruit M0 3.3V Micro-controller programmed in Circuit Pythong. 02/04/19 - fixed base on power resistor transistors still need to fix Q4 transistor should be EBC

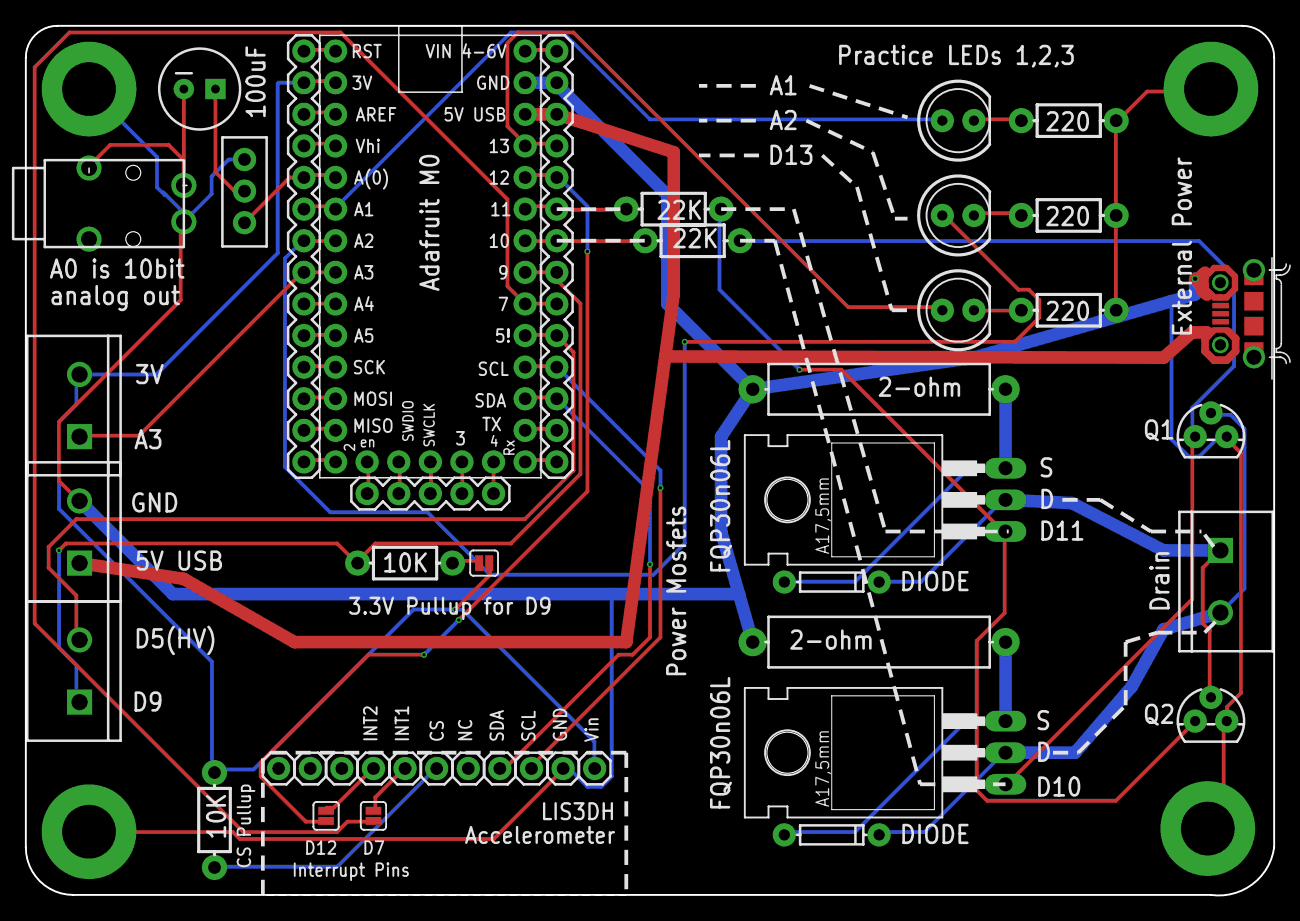
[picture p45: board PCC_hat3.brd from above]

Board: 2 copper layers, 100.3 x 69.9 mm, 48 parts (0 on the bottom side), 48 nets.

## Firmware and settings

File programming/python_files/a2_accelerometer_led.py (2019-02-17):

# you're using the lis3d_sh accelerometer
# with increasing tilt in the x-axis, more LEDs light up.

# I had to adjust Adafruit's lis3dh driver/library to work with the lis3d_sh accelerometer on your board.
# not all functions are working but it seems to read all axis and changes from 2g,4g,8g,16g!
# https://www.digikey.com/product-detail/en/stmicroelectronics/LIS3DSHTR/497-13244-1-ND/3635108

import time
import board
import digitalio
from digitalio import DigitalInOut, Direction
import busio
import lis3d_sh # this is NOT the lis3dh Adafruit accelerometer so this lis3d_sh library is used instead

i2c = busio.I2C(board.SCL, board.SDA)
int1 = digitalio.DigitalInOut(board.D7)  # Set to correct pin for interrupt!
accelerometer = lis3d_sh.LIS3DH_I2C(i2c, address=0x1D, int1=int1) #i2 address is 0x1D for the lis3d_sh

accelerometer.range = lis3d_sh.RANGE_8_G #options are 2g,4g,8g,16g

redLed = DigitalInOut(board.D13)
redLed.direction = Direction.OUTPUT
greenLed = DigitalInOut(board.A2)
greenLed.direction = Direction.OUTPUT
yellowLed = DigitalInOut(board.A1)
yellowLed.direction = Direction.OUTPUT

while True:
    x, y, z = [value / lis3d_sh.STANDARD_GRAVITY for value in accelerometer.acceleration]
    #print("x = %0.3f G, y = %0.3f G, z = %0.3f G" % (x, y, z))
    print((x,y,z))
    if x > 0.2:
        redLed.value = True
    else:
        redLed.value = False
    if x > 0.4:
        greenLed.value = True
    else:
        greenLed.value = False
    if x > 0.8:
        yellowLed.value = True
    else:
        yellowLed.value = False    
    
    time.sleep(0.05)

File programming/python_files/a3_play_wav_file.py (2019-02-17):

# 5 wav files for you try in the sounds folder
# uncomment out the files to play each sound file.. and/or make your own. 
#save files as 22 KHz or less because the circuitpython can't handle more data than that 
#(and also it will not sound much better) and the DAC output is 10-bit so anything over 16-bit will 
#just take up room without better quality.

# the monotonic() function is some seudo threading thing that allows the processor  to do other things while the wav file plays
# once you initiate Play the monotic while loop is TRUE for sec seconds as follows ... time.monotonic() - t < sec:

import time
import audioio
import board
import digitalio
 
button = digitalio.DigitalInOut(board.A1)
button.switch_to_input(pull=digitalio.Pull.UP)
 
wave_file = open("sounds/StreetChicken.wav", "rb") # 9 second long clip
#wave_file = open("sounds/end_of_the_world2.wav", "rb") # 3 second long clip
#wave_file = open("sounds/voice_mail.wav", "rb") # 20 second long clip lelft at 16bit
#wave_file = open("sounds/laugh.wav", "rb") # ~3 second long clip
#wave_file = open("sounds/rimshot.wav", "rb") # ~2 second long clip

wave = audioio.WaveFile(wave_file)
audio = audioio.AudioOut(board.A0)
 
while True:
    audio.play(wave)
    # This allows you to do other things while the audio plays!
    t = time.monotonic()
    while time.monotonic() - t < 10:
        pass

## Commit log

2019-02-17 Create soldering tutorial
2019-02-17 Update soldering tutorial
2019-02-23 updated solder instructions
2019-06-22 new class
    [PCC_hat3.brd, PCC_hat3.sch]
2019-06-22 Revert "new class"
    This reverts commit 5374a47602157a0fa1197a82c1c2d07d4dc48a7c.
    [PCC_hat3.brd, PCC_hat3.sch]

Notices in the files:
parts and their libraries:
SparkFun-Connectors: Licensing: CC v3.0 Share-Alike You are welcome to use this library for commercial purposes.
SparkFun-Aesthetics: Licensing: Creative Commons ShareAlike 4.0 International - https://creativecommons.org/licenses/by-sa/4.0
